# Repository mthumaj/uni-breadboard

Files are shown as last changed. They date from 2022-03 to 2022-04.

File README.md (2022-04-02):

# Universal Breadboard (uni-breadboard)

Breadboard based on 4mm banana plugs designed for easier connection of device with test environment while developing/debugging/testing.

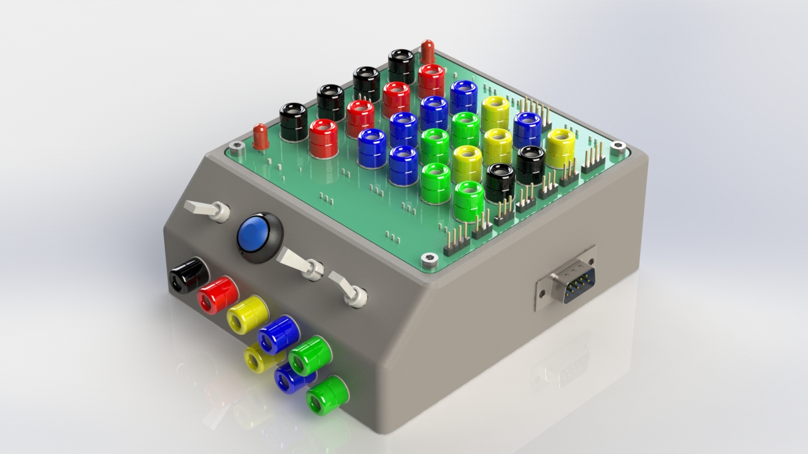
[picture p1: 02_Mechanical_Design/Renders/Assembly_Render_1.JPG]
Breadboard


**Features:**
* 24 banana plugs (4mm) screwed-in on custom PCB (10 x 10cm)
* Switch and button to power on/off - for easy power reset of device
* LIN Bus input (LIN_IN) with selection option to connect to LIN_1 or/and LIN_2 channel
* 2 D-SUB9 LIN/CAN interfaces
* 5 General purpose ports (A-E)
* D-SUB9 connector dedicated as port interface (optimized for Vector VN1640 Digital/Analog IO interface (CH5))

## Detailed Description

Breadboard is composed from PCB and 3D printed case/box. 
Plugs/connectors from case are connected to the PCB by wires and screw terminals. 

### Front Panel

**Banana plugs**

| Number 	| Signal 	|
| :---: 	| :---: 	|
| 1 		| GND 		|
| 2 		| V_OUT 	|
| 3 		| LIN_IN 	|
| 4 		| PORT_A 	|
| 5 		| PORT_B 	|
| 6 		| PORT_C 	|
| 7 		| PORT_D 	|
| 8 		| PORT_E 	|

*Note: Numbering starts from left

### Switches (from left)

**Power switch**
* Top position: 	Power OFF
* Bottom position:	Power ON (V_IN --> V_OUT)
	
**Power reset button** - only if Power switch is in bottom position (Power is ON)
* Released:			Power ON
* Pressed:			Power OFF
	
**LIN selector switch**
* Left position: 	LIN_IN --> LIN_1
* Middle position:	LIN_IN - not connected
* Right position:	LIN_IN --> LIN_2
	
**LIN_1 and LIN_2 connection switch**
* Top position: 	LIN_1 and LIN_2 not connected
* Bottom position:	LIN_1 and LIN_2 connected

### Back Panel

**Banana plugs**
| Number 	| Signal 	|
| :---: 	| :---: 	|
| 1 		| V_IN 		|
| 2 		| GND 		|

*Note: Numbering starts from left

**Right D-SUB9 Connector - LIN/CAN Interface 1**

| Number 	| Signal 			|
| :---: 	| :---: 			|
| 2 		| CAN_L_1 			|
| 3 		| GND 				|
| 7			| LIN_1/CAN_H_1		|

Others are not connected

**Left D-SUB9 Connector - LIN/CAN Interface 2**

| Number 	| Signal 			|
| :---: 	| :---: 			|
| 2 		| CAN_L_2 			|
| 3 		| GND 				|
| 7			| LIN_1/CAN_H_2		|

Others are not connected

### Right Panel

**D-SUB9 Connector - Analog/Digital Interface**

| Number 	| Signal 	|
| :---: 	| :---: 	|
| 1 		| A_IN 		|
| 2 		| NC 		|
| 3 		| NC 		|
| 4 		| D_IN_1 	|
| 5 		| D_IN_2 	|
| 6 		| A_GND 	|
| 7 		| NC	 	|
| 8 		| D_OUT 	|
| 9			| D_GND		|

*Refer to: https://cdn.vector.com/cms/content/products/VN16xx/docs/VN1600_Interface_Family_Manual_EN.pdf chapter 2.6.8*

Ports connection (PORT_A - PORT_E) to Analog/Digital Interface can be established by jumpers/wires on J7 

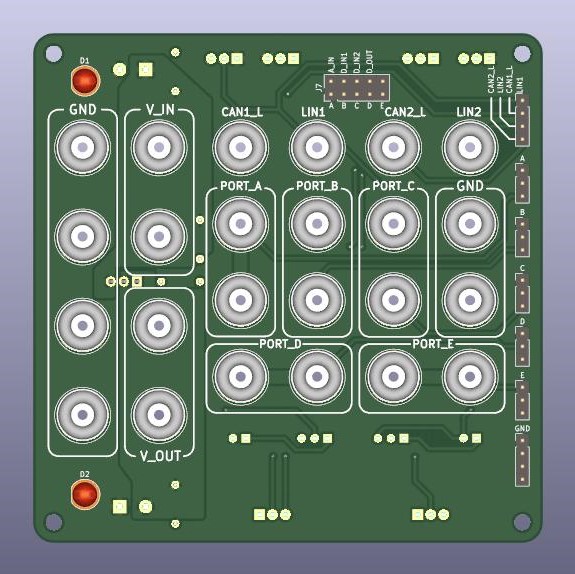
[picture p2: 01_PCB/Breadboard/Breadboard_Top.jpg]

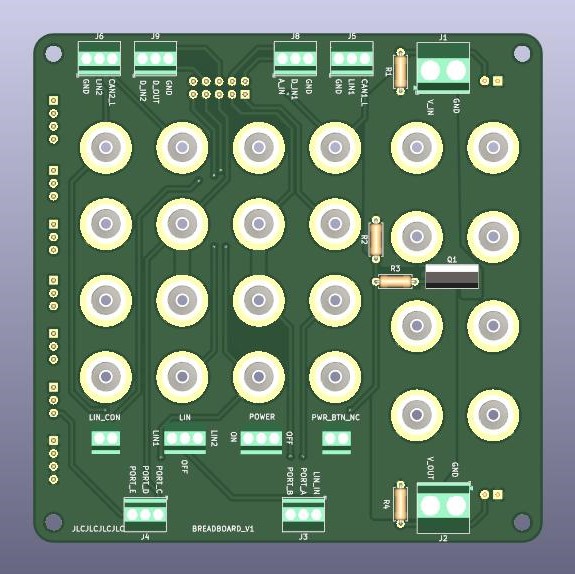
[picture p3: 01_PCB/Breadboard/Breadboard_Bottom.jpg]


## Build Manual/Notes

1. 3D Print breadboard case from [here](/02_Mechanical_Design/BreadboardBox_1.STL)
	* No supports needed
	* 0.6mm nozzle can be used to speed up printing
2. Insert and glue M3 hex nuts.
3. Assembly the PCB 
	* gerber files to manufacture are available [here](/01_PCB/Breadboard/gerbers)
	* BOM is available [here](BOM.xlsx)
	* When assembling screw terminals, make sure that wire openings are oriented inside the board (see picture), so wires can be easily inserted to the terminal, when board is already mounted on top of case.
4. Solder cables for banana plugs, switches and D-SUB9 connectors
	* For V_IN, V_OUT and GND connection use cable with cross section at least 1,5mm^2
5. Mount banana plugs/switches/D-SUB9 connectors to the case
	* When mounting banana plugs, use serrated lock washers (washer with "teeth") to prevent releasing when plug and unplug connectors to the plugs.
6. Connect wires to the respected screw terminals
7. ...and it's done.

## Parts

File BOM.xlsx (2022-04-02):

Qty | Reference(s) | Value | Order number (Farnell)
Schematic
1 | D1 | V_IN | 1581136 (https://eur04.safelinks.protection.outlook.com/?reserved=0)
1 | D2 | V_OUT | 1581136 (https://eur04.safelinks.protection.outlook.com/?reserved=0)
2 | J1, J2 | Screw_Terminal_01x02 | 3041165 (https://eur04.safelinks.protection.outlook.com/?reserved=0)
6 | J3, J4, J5, J6, J8, J9 | Screw_Terminal_01x03 | 3817461 (https://eur04.safelinks.protection.outlook.com/?reserved=0)
1 | J7 | Conn_02x05_Odd_Even | 3497342 (https://eur04.safelinks.protection.outlook.com/?reserved=0)
1 | Q1 | IRF4905 | 8648255 (https://eur04.safelinks.protection.outlook.com/?reserved=0)
2 | R1, R4 | 1K5 | 9339183 (https://eur04.safelinks.protection.outlook.com/?reserved=0)
1 | R2 | 10K | 9339060 (https://eur04.safelinks.protection.outlook.com/?reserved=0)
1 | R3 | 100R | 9339043 (https://eur04.safelinks.protection.outlook.com/?reserved=0)
1 | SW1 | SW_SPDT | 3817461 (https://eur04.safelinks.protection.outlook.com/?reserved=0)
1 | SW2 | SW_Push_Open | 3817460 (https://eur04.safelinks.protection.outlook.com/?reserved=0)
1 | SW3 | SW_SPST | 3817460 (https://eur04.safelinks.protection.outlook.com/?reserved=0)
1 | SW4 | SW_SPDT_MSM | 3817461 (https://eur04.safelinks.protection.outlook.com/?reserved=0)
Other
6 |  | Banana Plug 4mm (Red) | 1698950 (https://eur04.safelinks.protection.outlook.com/?reserved=0)
8 |  | Banana Plug 4mm (Black) | 1698951 (https://eur04.safelinks.protection.outlook.com/?reserved=0)
8 |  | Banana Plug 4mm (Blue) | 1698952 (https://eur04.safelinks.protection.outlook.com/?reserved=0)
6 |  | Banana Plug 4mm (Yellow) | 1698954 (https://eur04.safelinks.protection.outlook.com/?reserved=0)
6 |  | Banana Plug 4mm (Green) | 1698955 (https://eur04.safelinks.protection.outlook.com/?reserved=0)
1 |  | Power switch | 9473610 (https://eur04.safelinks.protection.outlook.com/?reserved=0)
1 |  | Power reset button | 2892238 (https://eur04.safelinks.protection.outlook.com/?reserved=0)
1 |  | LIN_1 and LIN_2 connection switch | 9473610 (https://eur04.safelinks.protection.outlook.com/?reserved=0)
1 |  | LIN selector switch | 9473629 (https://eur04.safelinks.protection.outlook.com/?reserved=0)
3 |  | D-SUB9 Male Connector | 1084672 (https://eur04.safelinks.protection.outlook.com/?reserved=0)
3 |  | D-SUB9 Screwlock pair | 2099517 (https://eur04.safelinks.protection.outlook.com/?reserved=0)
5 |  | 3x1 Pin Header, 2,54mm | 1593412 (https://eur04.safelinks.protection.outlook.com/?reserved=0)
2 |  | 4x1 Pin Header, 2,54mm | 1593413 (https://eur04.safelinks.protection.outlook.com/?reserved=0)

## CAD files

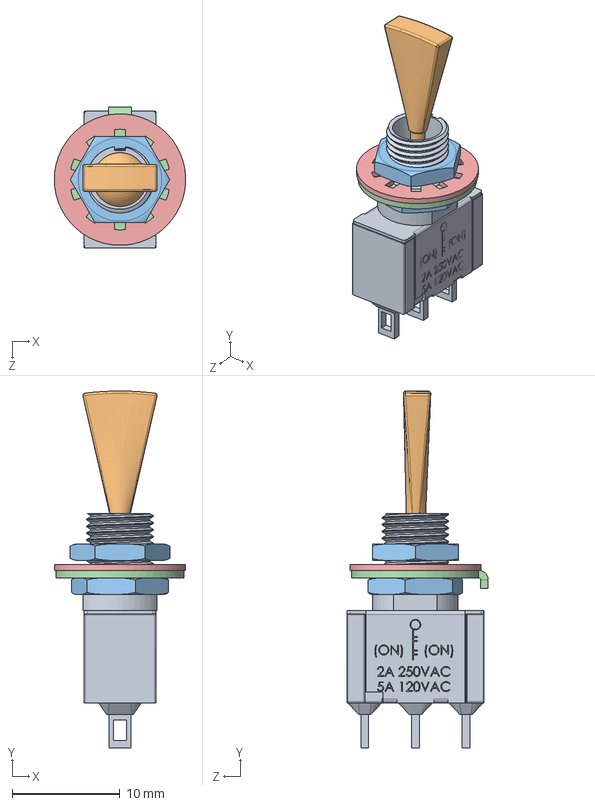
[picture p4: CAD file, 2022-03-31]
02_Mechanical_Design/Components/Flip Switch Assem.SLDASM
12.2 x 33.1 x 13.1 mm
Flip Switch Base
Flip Switch
Nut 1,5x8 4-40 x 2
Washer Lock
internal tooth lock washer_am

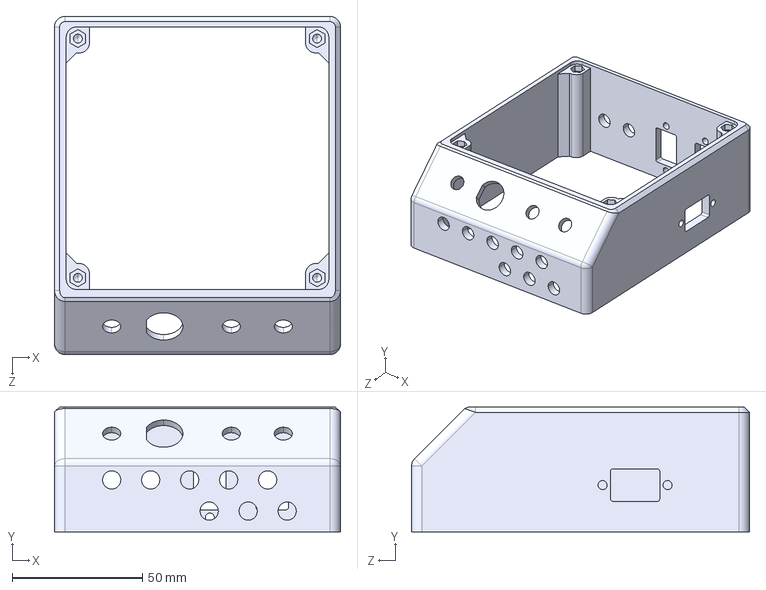
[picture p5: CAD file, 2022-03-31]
02_Mechanical_Design/BreadboardBox_1.STEP
110.0 x 48.0 x 130.0 mm

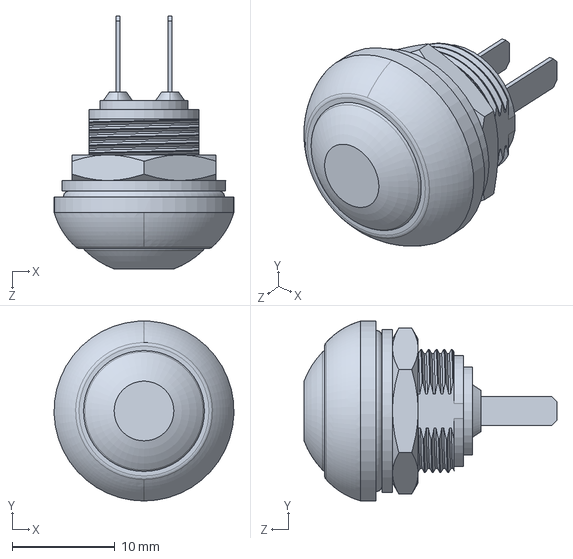
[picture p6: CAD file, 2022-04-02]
02_Mechanical_Design/Components/Pushbutton_1-2329383-5.SLDPRT
17.5 x 17.5 x 24.6 mm

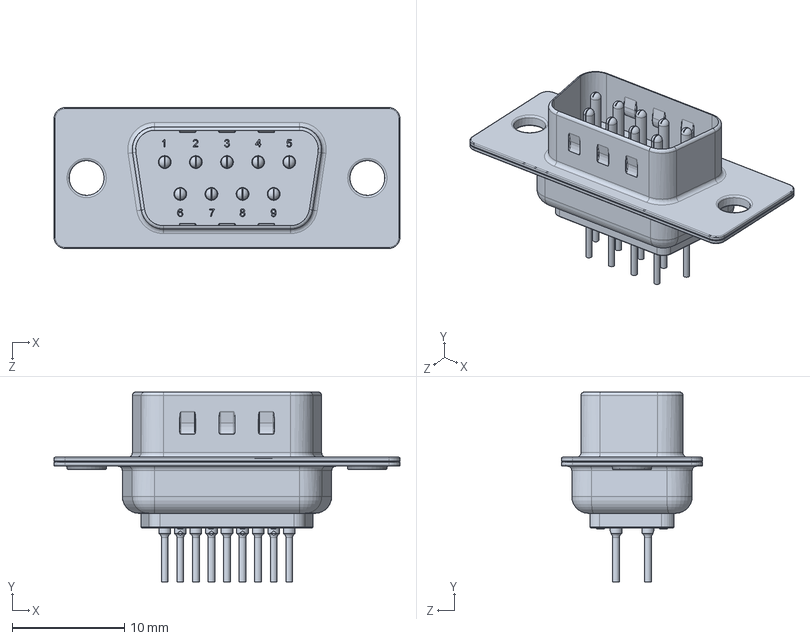
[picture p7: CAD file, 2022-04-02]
02_Mechanical_Design/Components/D-SUB_9.SLDPRT
30.8 x 16.9 x 12.6 mm

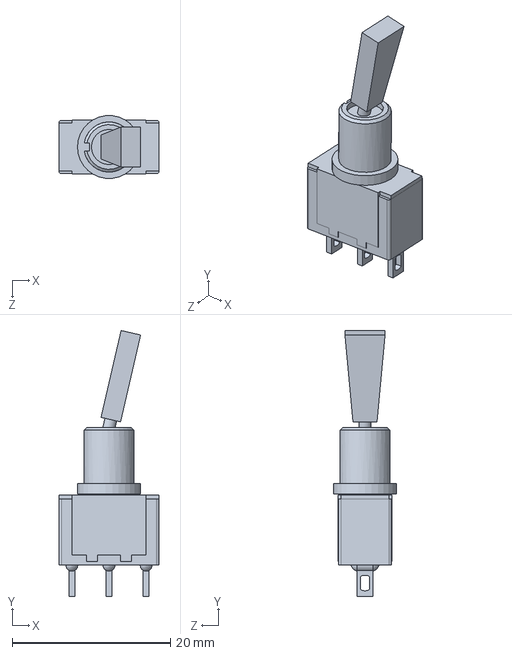
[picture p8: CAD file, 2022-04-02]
02_Mechanical_Design/Components/switch_1ms3t6b11m1qe.SLDPRT
12.7 x 33.7 x 7.93 mm

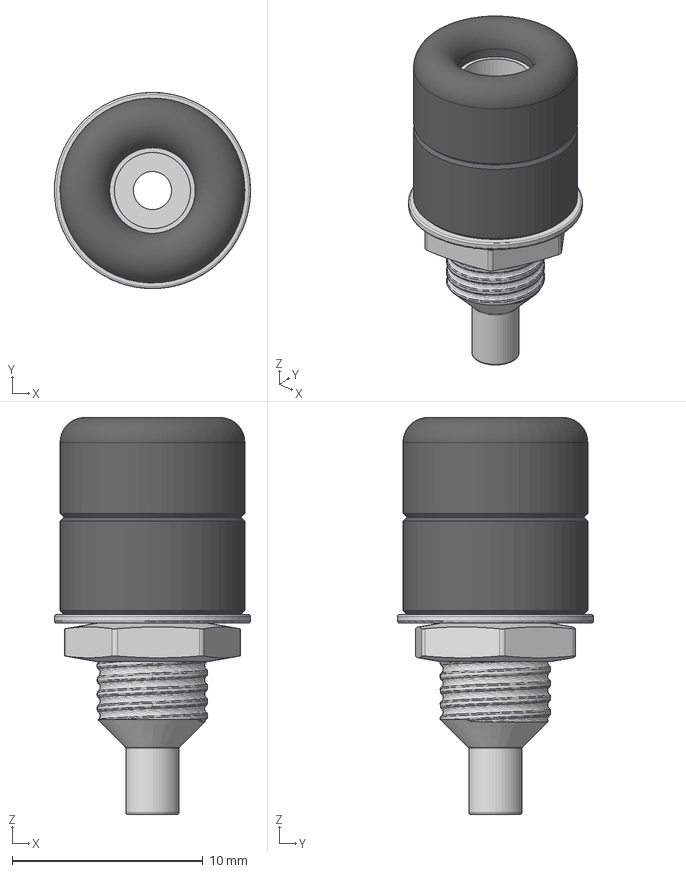
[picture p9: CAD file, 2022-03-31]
02_Mechanical_Design/Components/4mm_banana_socket.stp
10.3 x 10.3 x 20.8 mm
screw
cap_top
cap_bot
rondelle
ecrou

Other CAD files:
02_Mechanical_Design/BreadboardBox_1.SLDPRT
02_Mechanical_Design/BreadboardBox_1.STL
02_Mechanical_Design/Components/4mm_banana_socket.SLDASM

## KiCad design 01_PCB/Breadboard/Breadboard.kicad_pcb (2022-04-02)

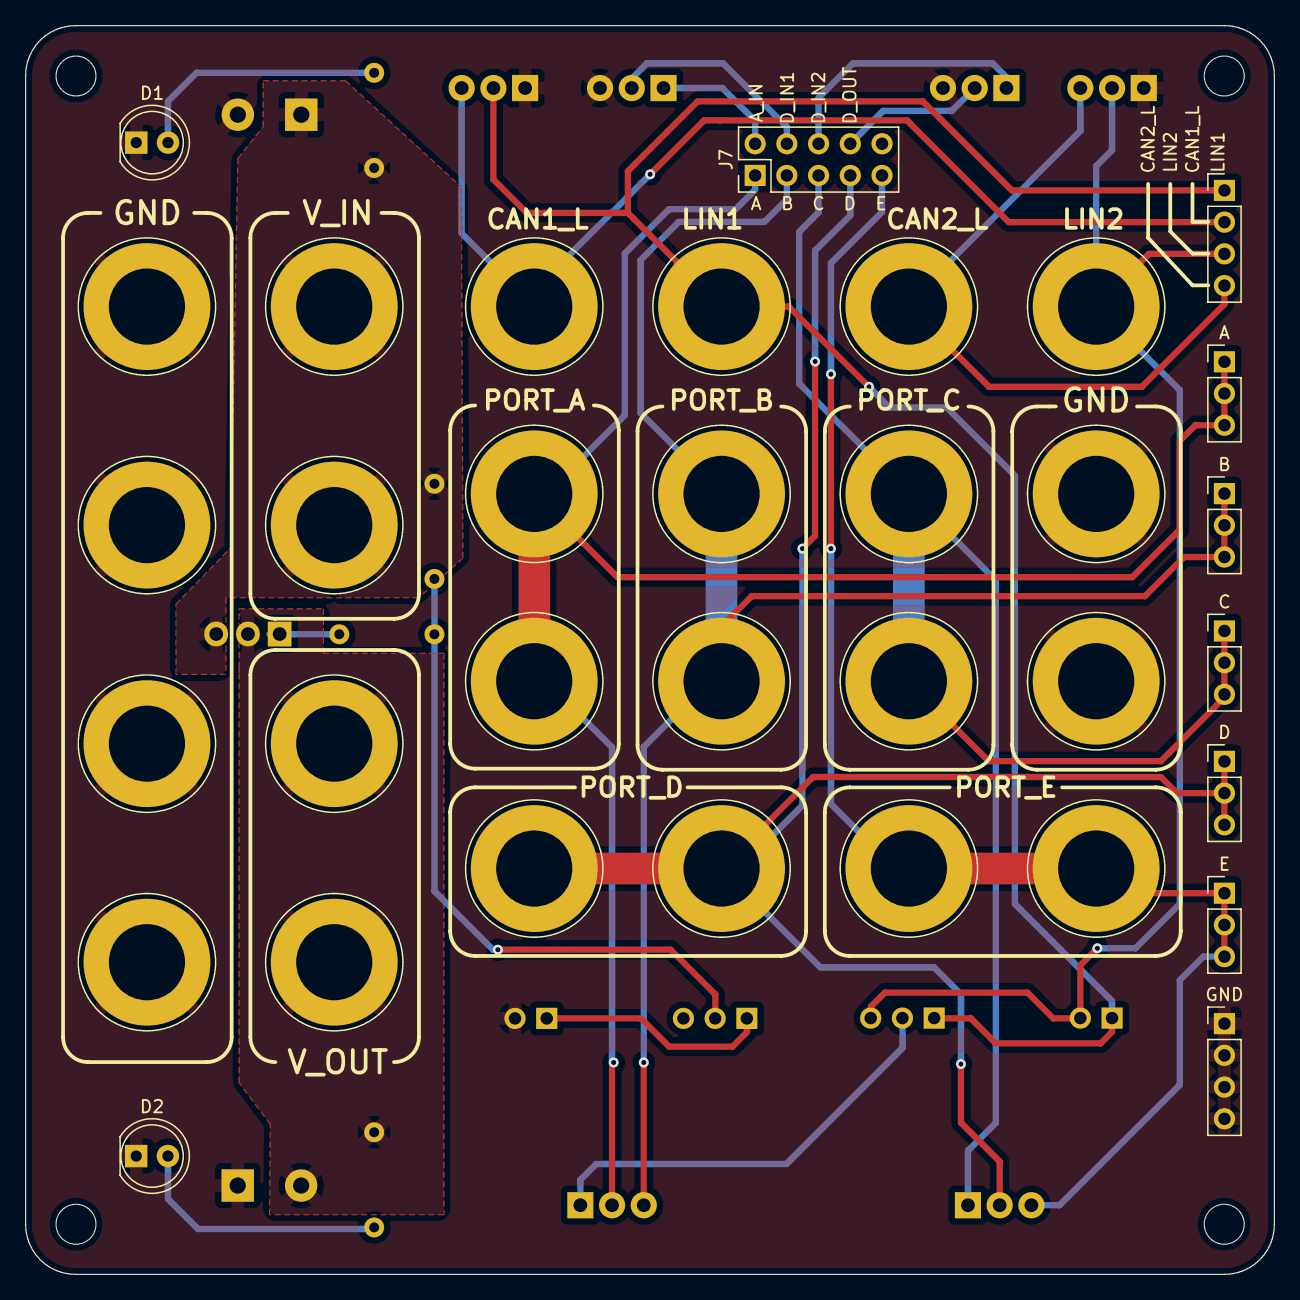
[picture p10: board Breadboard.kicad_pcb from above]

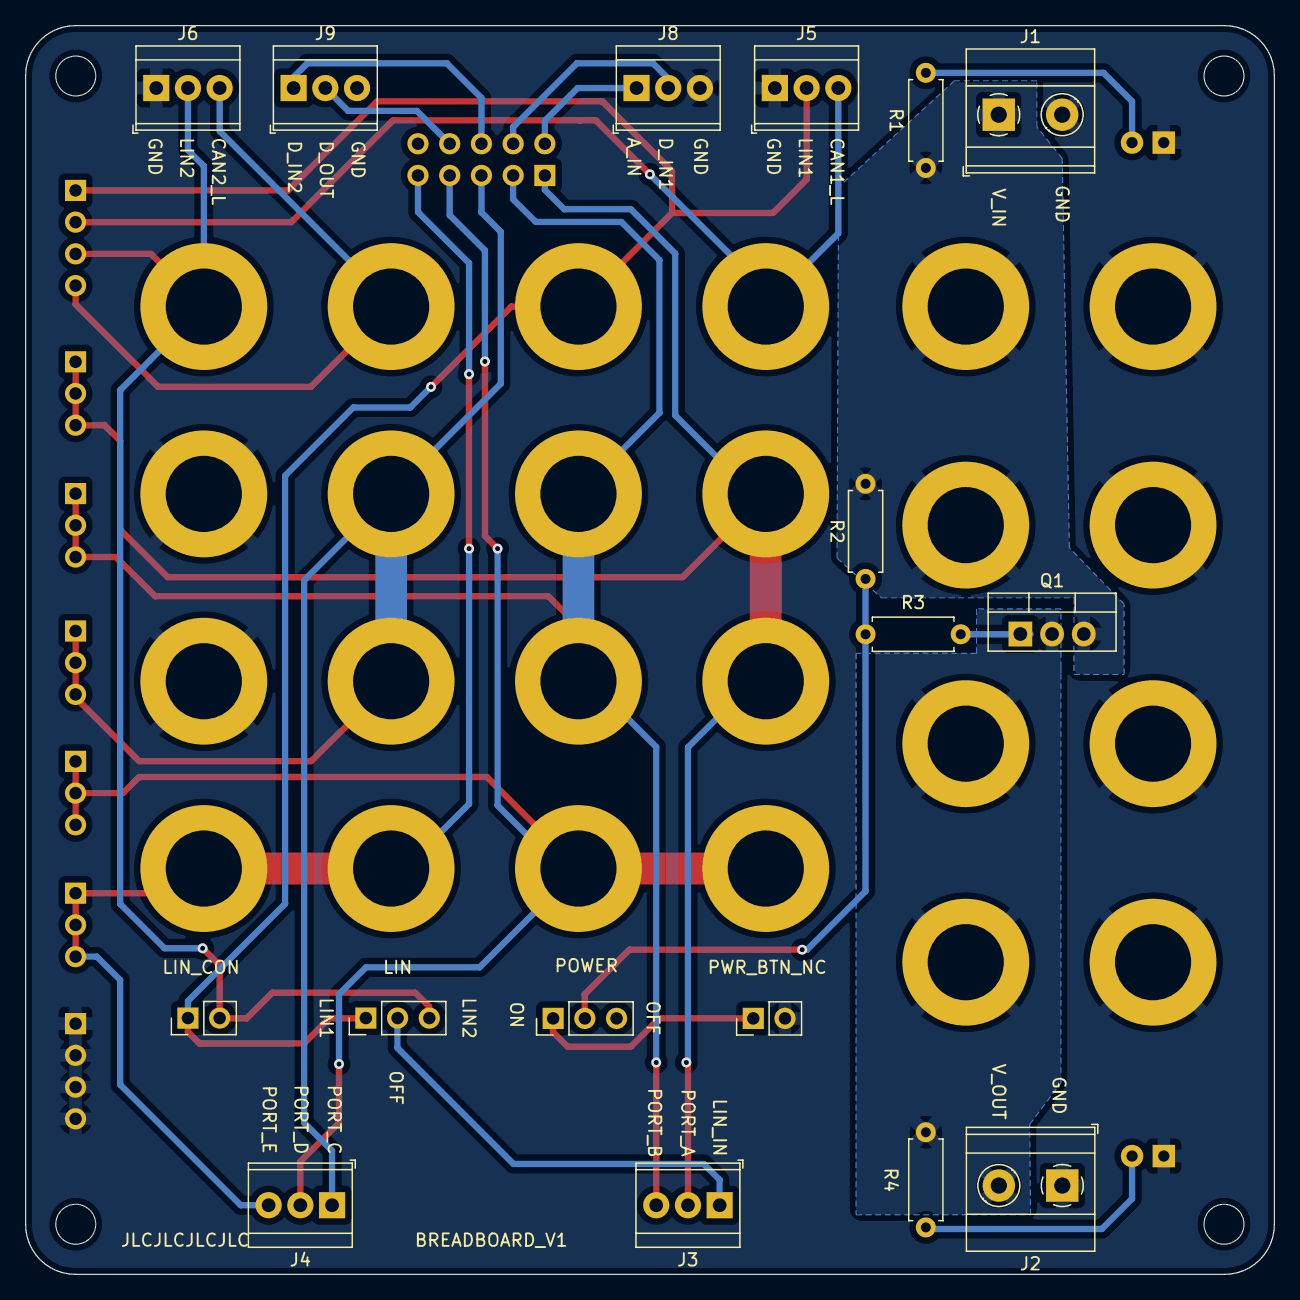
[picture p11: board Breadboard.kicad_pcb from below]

Board: 2 copper layers, 100.0 x 100.0 mm, 26 parts (17 on the bottom side), 20 nets.

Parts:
A: PinHeader_1x03_P2.54mm_Vertical
B: PinHeader_1x03_P2.54mm_Vertical
C: PinHeader_1x03_P2.54mm_Vertical
D: PinHeader_1x03_P2.54mm_Vertical
D1: V_IN; LED_D5.0mm
D2: V_OUT; LED_D5.0mm
E: PinHeader_1x03_P2.54mm_Vertical
GND: PinHeader_1x04_P2.54mm_Vertical
J1, J2: Screw_Terminal_01x02; TerminalBlock_Phoenix_MKDS-1,5-2-5.08_1x02_P5.08mm_Horizont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
J3, J4, J5, J6, J8, J9: Screw_Terminal_01x03; TerminalBlock_TE_282834-3_1x03_P2.54mm_Horizontal
J7: Conn_02x05_Odd_Even; PinHeader_2x05_P2.54mm_Vertical
LIN: SW_SPDT_MSM; PinHeader_1x03_P2.54mm_Vertical
LIN_CON: SW_SPST; PinHeader_1x02_P2.54mm_Vertical
POWER: SW_SPDT; PinHeader_1x03_P2.54mm_Vertical
PWR_BTN_NC: SW_Push_Open; PinHeader_1x02_P2.54mm_Vertical
Q1: IRF4905; TO-220-3_Vertical
R1, R4: 560R; R_Axial_DIN0207_L6.3mm_D2.5mm_P7.62mm_Horizontal
R2: 10K; R_Axial_DIN0207_L6.3mm_D2.5mm_P7.62mm_Horizontal
R3: 100R; R_Axial_DIN0207_L6.3mm_D2.5mm_P7.62mm_Horizontal

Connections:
/A_IN: J7.2, J8.1
/D_IN_1: J7.4, J8.2
/D_IN_2: J7.6, J9.1
/D_OUT: J7.8, J9.2
/PORT_A: A.1, A.2, A.3, J3.2, J7.1
/PORT_B: B.1, B.2, B.3, J3.3, J7.3
/PORT_C: C.1, C.2, C.3, J4.1, J7.5
/PORT_D: D.1, D.2, D.3, J4.2, J7.7
/PORT_E: E.1, E.2, E.3, J4.3, J7.9
CAN_H_1: J5.2, LIN.1, LIN_CON.1 (A)
CAN_H_2: J6.2, LIN.3, LIN_CON.2 (B)
GND: D1.1 (K), D2.1 (K), GND.1, GND.2, GND.3, GND.4, J1.2, J2.1, J5.1, J6.1, J8.3, J9.3, PWR_BTN_NC.2 (B)
LIN_IN: J3.1, LIN.2
unnamed: D1.2 (A), R1.2
unnamed: D2.2 (A), R4.2
unnamed: Q1.1 (G), R3.1
unnamed: POWER.2 (B), R2.2, R3.2
unnamed: POWER.1 (A), PWR_BTN_NC.1 (A)
VIN: J1.1, Q1.3 (S), R1.1, R2.1
VOUT: J2.2, Q1.2 (D), R4.1

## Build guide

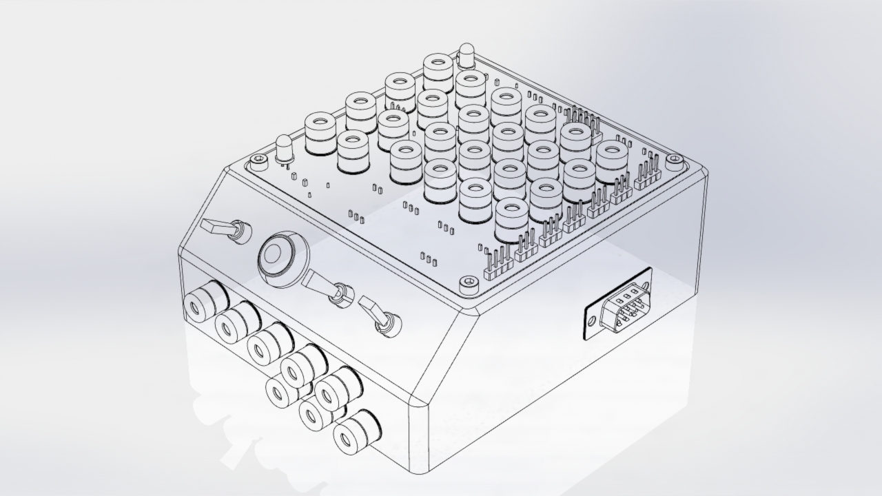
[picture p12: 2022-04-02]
02_Mechanical_Design/Renders/Assembly_Render_2.JPG

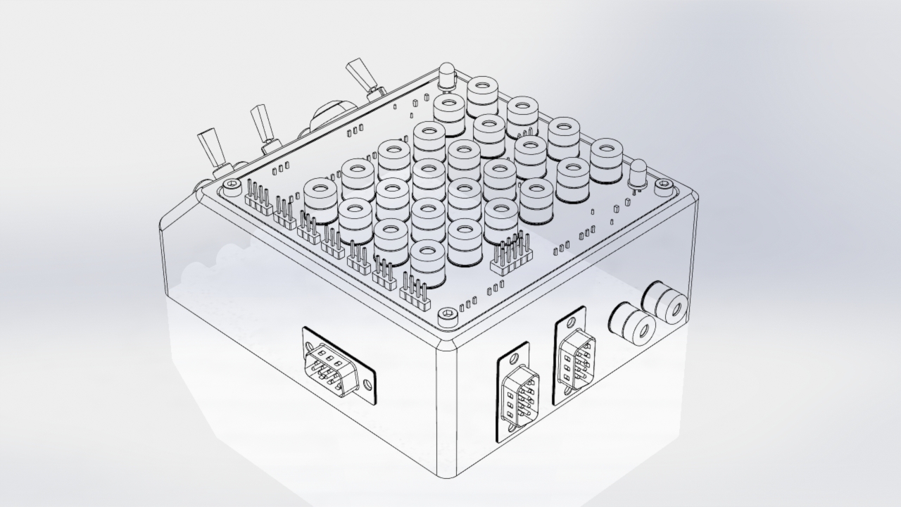
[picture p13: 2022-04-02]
02_Mechanical_Design/Renders/Assembly_Render_3.JPG

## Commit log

2022-03-31 Update PCB
    [4mm_banana_socket.stp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]
2022-03-31 Update mechanical parts
    [4mm_banana_socket.SLDASM, 4mm_banana_socket.stp, BreadboardBox_1.SLDPRT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]
2022-04-02 Add README.md, Add renders
    [4mm_banana_socket.SLDASM, BreadboardBox_1.SLDPRT, D-SUB_9.SLDPRT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]
2022-04-02 Fix top silkscreen
    Generate new gerbers.
    [Breadboard-B_Cu.gbl, Breadboard-B_Mask.gbs, Breadboard-B_Silkscreen.gbo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]
2022-04-02 Upload BOM
    [BOM.xlsx, Breadboard.kicad_sch]
2022-04-02 Fix link to .STL file
